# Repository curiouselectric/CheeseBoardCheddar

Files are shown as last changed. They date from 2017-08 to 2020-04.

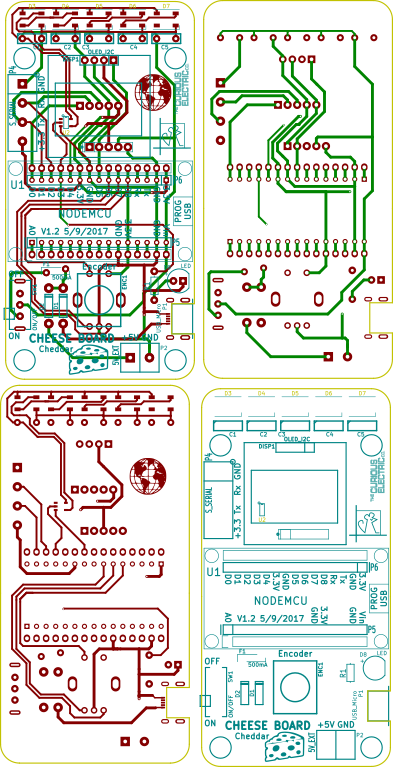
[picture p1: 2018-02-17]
CheeseBoardCheddar_Instructions/cheese_board_pcb.png

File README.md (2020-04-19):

# Cheese Board - Cheddar

This is an ESP8266 breakout board with small display, user inputs and WS2812 LEDs. 

This is designed as a low cost platform to quickly get started with projects with the ESP8266. We wanted to design something that got you up and running with your project idea quickly and easily.

The main processor is based upon the [ESP8266 system-on-chip from Espressif Systems](https://en.wikipedia.org/wiki/ESP8266).

This can be programmed via the Arduino IDE (or your favourite IDE).

This repository contains the design files, software and hardward files for this project.

We can supply this project in kit form from [The Curious Electric Company](https://www.curiouselectric.co.uk/) and Tindie.

This repository is for the hardware and instructions only. The software is available here:

https://github.com/curiouselectric/CheeseBoard_Software

## Instructions

The instructions are available in this folder as a .pdf

## PCB Overview

It is based upon the NodeMCU Amica ESP8266 module which is low-cost, easy to find and has all regulation and protection required.

There is a small I2C interfaced OLED screen on the unit for displaying data and options.

A rotary encoder is used to select various options and as the user interface.

There are five WS2812 LEDs which can be controlled via the ESP8266, along with a level shifter for good 5V operation.

A connection output is provided for HC12 wireless modules and access to a software serial output is provided through screw terminal pads.

This can be powered via USB-B or Micro-USB connector.

A screw-temrinal connector for 5V power is also supplied, if needed.

PCB design has been produced using [KiCAD](http://kicad-pcb.org/).

Hardware for the enclosure is also provided here.

### Pin Connections:

| Node MCU Conenction | Pin Number |Function | Arduino Alias |
|---|---|---|---|
| D0 | 30 | HC-12 SET pin | 16 |
| D1 | 29 | Soft Serial Tx | 5 |
| D2 | 28 | Soft Serial Rx | 4 |
| D3 | 27 | LED WS2812 | 0 |
| D4 | 26 | I2C SCLK | 2 |
| D5 | 23 | I2C SDA | 14 |
| D6 | 22 | Enocder B | 12 |
| D7 | 21 | Enocder A | 13 |
| D8 | 20 | Encoder Switch | 15 |
| D9 | 19 | H/W Serial Rx | 3 |
| D10 | 18 | H/W Serial Tx | 1 |
| A0 | 1 | N/C | A0 |

## Software Overview

This project has been designed with some interesting software to get you up and running. We wanted this project to do something useful or fun straight away. But it has been designed for hacking and for you to change, alter, adjust and play as you need.

## Hardware Overview

This kit comes with a simple enclosure to house the electronics.

This has been designed to be laser cut in 3mm acrylic. The design files are within this repository, if you would like to make your own or alter the design at all.

# To Do

* Check software in many applications
* Update instructions as required

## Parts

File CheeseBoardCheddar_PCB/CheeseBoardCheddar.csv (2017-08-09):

Reference | Value | Footprint | Datasheet | Description | Supplier 1 | Supplier 1 Part No | Supplier 1 Cost | Manufacturer | Manufacturer Part No
U1 | NODEMCU | REInnovationFootprint:NodeMCU_Amica_R2_FSILK | https://nodemcu.readthedocs.io/en/master/en/ | Node MCU Amica version. ESP8266 breakout. | AliExpress | https://www.aliexpress.com/item/Update-Industry-4-0-New-esp8266-NodeMCU-v2-Lua-WIFI-networking-development-kit-board-based-on/32358722888.html | 3.50
DISP1 | OLED_I2C | REInnovationFootprint:TH_OLED1306 |  | OLED display 128x64 IIC | Aliexpress | https://www.aliexpress.com/item/Free-Shipping-10pcs-2015-white-New-128X64-OLED-LCD-LED-Display-Module-0-96-I2C-IIC/32311828903.html | 2.75
D8 | LED | REInnovationFootprint:TH_LED-5MM_larg_pad |  |  |  |  | 0.05
P3 | SERIAL_HC12 | REInnovationFootprint:TH_SIL_5_HC12
R1 | 330 | REInnovationFootprint:TH_Resistor_1 |  |  |  |  | 0.01
SW1 | ON/OFF | REInnovationFootprint:SW_SPDT_R_Angle_ALIEX |  |  | Aliexpress |  | 0.2
F1 | 500mA | REInnovationFootprint:TH_MC36188_FUSE |  | Resettable fuse. 0.5A | RS | 517-6635 | 0.27
P6 | NODEMCU_2 | REInnovationFootprint:TH_SIL-15
P5 | NODEMCU_1 | REInnovationFootprint:TH_SIL-15
U2 | 74LVC1G17 | REInnovationFootprint:SM_SOT-23-5 | http://docs-europe.electrocomponents.com/webdocs/154d/0900766b8154d6d1.pdf |  | RS | 816-8763 | 0.06 | Nexperia | 74LVC1G17GV
P4 | S_SERIAL | matts_components:SIL-4_screw_terminals
P7 | PCB | REInnovationFootprint:PCB_50x100mm_RJWIFI
P10 | LOGO1 | CuriousElectric3:CEC_Globe_10mm_FCU
P11 | LOGO2 | CuriousElectric3:TCEC_Words_13mm
D1 | 1N5819 | REInnovationFootprint:TH_Diode_1 | https://www.diodes.com/assets/Datasheets/ds23001.pdf | 1A Schottky diode | RS | 917-9108 | 0.02 | HY Electronic Corp
ENC1 | Encoder | REInnovationFootprint:TH_Encoder |  | Rotary encoder | Aliexpress | https://www.aliexpress.com/item/Wholesale-20pcs-lot-12mm-Rotary-Encoder-Switch-W-Keyswitch-HQ-New-free-shipping-10000002/495026832.html | 0.50
P2 | 5V_EXT | matts_components:SIL-2_screw_terminal |  | Screw terminal conenctor | Aliexpress |  | 0.10
C1 | 100n | matts_components:C1_wide_lg_pad |  |  | Rapid | 10-3260 | 0.07
P1 | USB_Micro | REInnovationFootprint:USB_Micro-B_MOLEX_47642-0001 | http://docs-europe.electrocomponents.com/webdocs/144c/0900766b8144c28e.pdf | Micro USB connector | RS | 896-7419 | 0.60 | MOLEX | 47642-0001
D2 | 1N5819 | REInnovationFootprint:TH_Diode_1 | https://www.diodes.com/assets/Datasheets/ds23001.pdf | 1A Schottky diode | RS | 917-9108 | 0.02 | HY Electronic Corp
P9 | HARDWARE | CuriousElectric3:CEC_Globe_10mm_FCU
P8 | LOGO_MOUSE | CuriousElectric3:CEC_Globe_10mm_FCU
D3 | WS2812B_SMD | REInnovationFootprint:SM_WS2812B | https://www.kitronik.co.uk/pdf/WS2812B-LED-datasheet.pdf | WS2812B SMD 50_50 | AliExpress | https://www.aliexpress.com/item/10-1000pcs-WS2812B-4pins-5050-SMD-Black-White-version-WS2812-Individually-Addressable-Digital-RGB-LED-Chip/ | 0.10
D4 | WS2812B_SMD | REInnovationFootprint:SM_WS2812B | https://www.kitronik.co.uk/pdf/WS2812B-LED-datasheet.pdf | WS2812B SMD 50_50 | AliExpress | https://www.aliexpress.com/item/10-1000pcs-WS2812B-4pins-5050-SMD-Black-White-version-WS2812-Individually-Addressable-Digital-RGB-LED-Chip/ | 0.10
D5 | WS2812B_SMD | REInnovationFootprint:SM_WS2812B | https://www.kitronik.co.uk/pdf/WS2812B-LED-datasheet.pdf | WS2812B SMD 50_50 | AliExpress | https://www.aliexpress.com/item/10-1000pcs-WS2812B-4pins-5050-SMD-Black-White-version-WS2812-Individually-Addressable-Digital-RGB-LED-Chip/ | 0.10
D6 | WS2812B_SMD | REInnovationFootprint:SM_WS2812B | https://www.kitronik.co.uk/pdf/WS2812B-LED-datasheet.pdf | WS2812B SMD 50_50 | AliExpress | https://www.aliexpress.com/item/10-1000pcs-WS2812B-4pins-5050-SMD-Black-White-version-WS2812-Individually-Addressable-Digital-RGB-LED-Chip/ | 0.10
D7 | WS2812B_SMD | REInnovationFootprint:SM_WS2812B | https://www.kitronik.co.uk/pdf/WS2812B-LED-datasheet.pdf | WS2812B SMD 50_50 | AliExpress | https://www.aliexpress.com/item/10-1000pcs-WS2812B-4pins-5050-SMD-Black-White-version-WS2812-Individually-Addressable-Digital-RGB-LED-Chip/ | 0.10
C2 | 100n | matts_components:C1_wide_lg_pad |  |  | Rapid | 10-3260 | 0.07
C3 | 100n | matts_components:C1_wide_lg_pad |  |  | Rapid | 10-3260 | 0.07
C4 | 100n | matts_components:C1_wide_lg_pad |  |  | Rapid | 10-3260 | 0.07
C5 | 100n | matts_components:C1_wide_lg_pad |  |  | Rapid | 10-3260 | 0.07

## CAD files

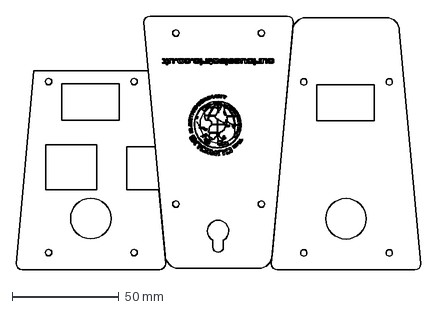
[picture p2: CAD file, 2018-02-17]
CheeseBoardCheddar_Hardware/Cheese Board Cheddar Enclosure Design_v2.dxf
189.4 x 118.8 mm

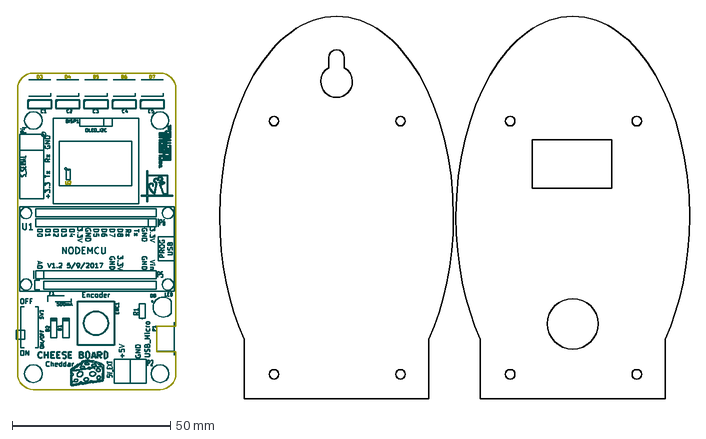
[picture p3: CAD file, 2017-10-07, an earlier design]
CheeseBoardCheddar_Hardware/OLD designs/Cheese Board Cheddar Enclosure Design.dxf
212.7 x 120.8 mm

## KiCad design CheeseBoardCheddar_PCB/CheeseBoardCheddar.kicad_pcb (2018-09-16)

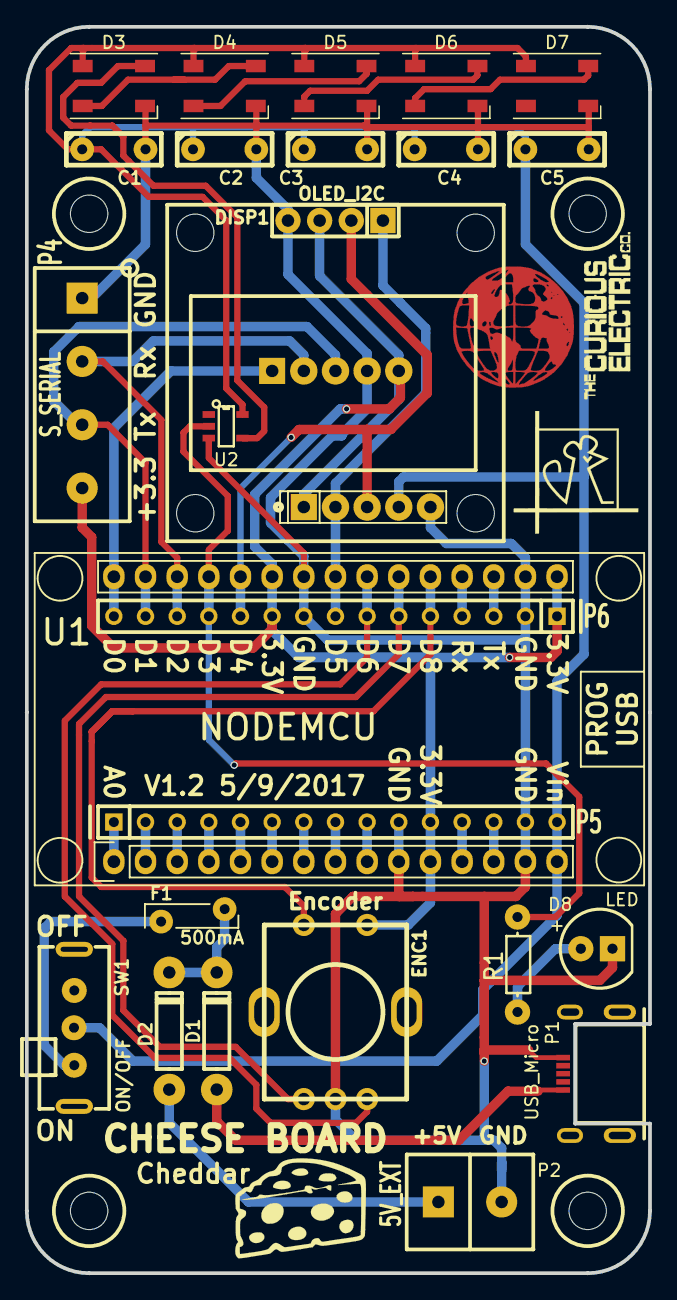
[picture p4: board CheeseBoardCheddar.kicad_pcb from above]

Board: 2 copper layers, 50.0 x 100.0 mm, 32 parts (0 on the bottom side), 35 nets.

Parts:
C1, C2, C3, C4, C5: 100n; C1_wide_lg_pad
D1, D2: 1N5819; TH_Diode_1
D3, D4, D5, D6, D7: WS2812B_SMD; SM_WS2812B
D8: LED; TH_LED-5MM_larg_pad
DISP1: OLED_I2C; TH_OLED1306
ENC1: Encoder; TH_Encoder
F1: 500mA; TH_MC36188_FUSE
P1: USB_Micro; USB_Micro-B_MOLEX_47642-0001
P2: 5V_EXT; SIL-2_screw_terminal
P3: SERIAL_HC12; TH_SIL_5_HC12
P4: S_SERIAL; SIL-4_screw_terminals
P5: NODEMCU_1; TH_SIL-15
P6: NODEMCU_2; TH_SIL-15
P7: PCB; PCB_50x100mm_RJWIFI
P8: LOGO_MOUSE; mouse10x10
P10: LOGO1; CEC_Globe_10mm_FCU
P11: LOGO2; TCEC_Words_13mm
P13: LOGO_CHEESE; CheeseWedge8mm
P14: I2C_EXT; SIL-5_large_pads_marker
R1: 330; TH_Resistor_1
SW1: ON/OFF; SW_SPDT_R_Angle_ALIEX
U1: NODEMCU; NodeMCU_Amica_R2_FSILK
U2: 74LVC1G17; SM_SOT-23-5

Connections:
+3V3: DISP1.3, ENC1.2, P3.5, P4.4, P5.11, P6.1, P6.10, P14.1, U1.11, U1.16, U1.25
/5V_PWR: C1.1, C2.1, C3.1, C4.1, C5.1, D3.1, D4.1, D5.1, D6.1, D7.1, P5.15, P14.4, SW1.2, U1.15, U2.5
/ENC_A: ENC1.A, P6.6, U1.21
/ENC_B: ENC1.B, P6.7, U1.22
/HC12_SET: P3.1, P6.15, U1.30
/LED_WS2811: P6.12, R1.1, U1.27, U2.2
/Rx: P6.4, U1.19
/SCL: DISP1.2, P6.11, P14.3, U1.26
/SDA: DISP1.1, P6.8, P14.2, U1.23
/SOFT_Rx: P3.2, P4.2, P6.13, U1.28
/SOFT_Tx: P3.3, P4.3, P6.14, U1.29
/SW_ENC: ENC1.1, P6.5, U1.20
/Tx: P6.3, U1.18
GND: C1.2, C2.2, C3.2, C4.2, C5.2, D3.3, D4.3, D5.3, D6.3, D7.3, D8.1, DISP1.4, ENC1.C, P1.5, P2.2, P3.4, P4.1, P5.10, P5.14, P6.2, P6.9, P14.5, U1.10, U1.14, U1.17, U1.24, U2.3
unnamed: D1.1, D2.1, F1.1
unnamed: D1.2, P1.1
unnamed: D2.2, P2.1
unnamed: D3.2, D4.4
unnamed: D3.4, U2.4
unnamed: D4.2, D5.4
unnamed: D5.2, D6.4
unnamed: D6.2, D7.4
unnamed: D8.2, R1.2
unnamed: F1.2, SW1.1
unnamed: P5.1, U1.1
unnamed: P5.2, U1.2
unnamed: P5.3, U1.3
unnamed: P5.4, U1.4
unnamed: P5.5, U1.5
unnamed: P5.6, U1.6
unnamed: P5.7, U1.7
unnamed: P5.8, U1.8
unnamed: P5.9, U1.9
unnamed: P5.12, U1.12
unnamed: P5.13, U1.13

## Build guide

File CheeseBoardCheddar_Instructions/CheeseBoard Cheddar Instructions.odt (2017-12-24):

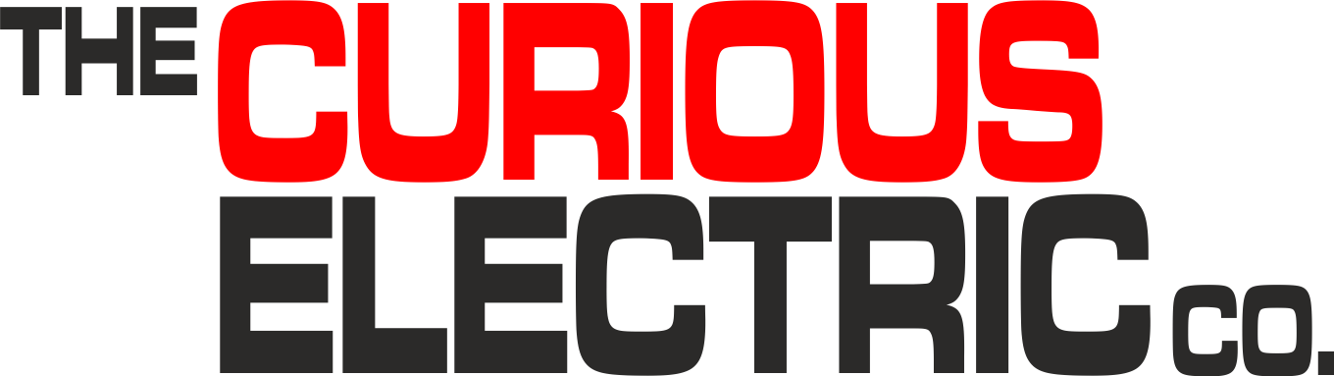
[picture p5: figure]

| Cheese Board: Cheddar Instructions

Date: | 24/09/17 | Version: | 1.0 | By: | Matt Little

This is an ESP8266 breakout board with small OLED display, a rotary encoder for user input and five Red-Green-Blue WS2812 LEDs.

This is designed as a low cost platform to quickly get started with projects with the ESP8266. We wanted to design something that got you up and running with your project idea quickly and easily.

The main processor is based upon the ESP8266 system-on-chip from Espressif Systems (https://en.wikipedia.org/wiki/ESP8266).

This can be programmed via the Arduino IDE (or your favourite IDE).

This is a reasonably simple kit which requires some soldering.

This kit requires a micro-USB lead for programming and powering the unit.

It should take 1-2 hours to build.

Not suitable for under 12 years old.

# Parts included:

# Enclosure Parts:

# Parts list:

Item | Ref | Quantity
Capacitors. 100nf | C1-5 | 5
Diode. 1N5819 | D1, D2 | 2
LED. WS2812 (pre soldered) | D3-7 | 5
LED. Red. NOT included | B8 | Not Included
Display. OLED. 0.96" With 4-way header | DISP1 | 1
Encoder | ENC1 | 1
Fuse. 500MA | F1 | 1
USB micro Socket (pre-soldered) | P1 | 1
2 way screw terminal. 5V | P2 | 1
HC-11 Serial. Optional | P3
Software Serial. Optional | P4
Node MCU header. 15 way. | P5, P6 | 2
PCB – with SMD parts soldered | | 1
330ohm Resistor | R1 | 1
Switch | SW1 | 1
NodeMCU with 2 x 15 way headers | U1
74LVC1G17 Level shifter (pre-soldered) | U2

# Hardware

Item | Ref | Quantity
M2 Machine screws. Plastic. 6mm long | | 2
M2 Nuts. Plastic | | 2
M2 Spacers. Plastic. 12mm long | | 2
M3 Machine screws. 6mm long | | 4
M3 Machine screws 12mm long | | 4
M3 Threaded Hex spacers. 8mm long | | 4
M3 Threaded Hex spacers. 15mm long | | 4
Front. Laser cut 3mm Frosted Acrylic | | 1
Spacer. Laser cut 3mm Black. Acrylic | | 1
Back. Laser cut 3mm Frosted Acrylic | | 1

# Tools required:

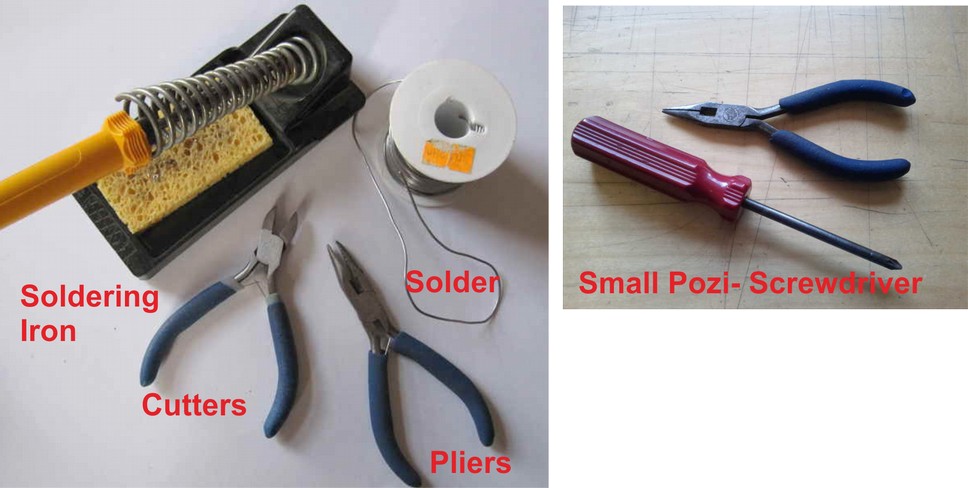
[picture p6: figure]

| | Long-nosed Pliers
Soldering Iron | | Posi-drive Screwdriver
Solder
Side cutters

Additional Items Required

- 1 x Micro-USB lead (for powering and for programming)
- 1 x 5V USB power supply (might be required for powering stand-alone unit)
- Computer with Arduino IDE and additional software installed. (see software section for more details)

Instructions:

Step: 1 | Solder capacitors

Step: 2 | Solder diodes

Step: 3 | Solder switch

Step: 4 | Solder header pins
| | For OLED and for NodeMCU

Step: 5 | Solder encoder

Step: 6 | Solder fuse

Step: 7 | Solder screw terminals (if needed)

Step: 8 | Fit LCD

Step: 9 | Fit Node MCU

Step: 10 | PCB is finished!

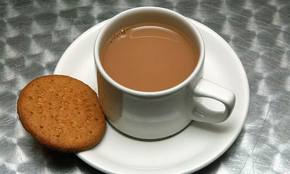
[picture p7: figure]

The NodeMCU has been pre-programmed with a test code. This should run when powered. Test with micro-USB cable. Switch on and check: LEDs light OLED screen shows data Rotary Encoder changes data on OLED This should prove that the functions of the PCB and the NodeMCU are working OK. | | Have a nice cup of tea.

Step: 11 | Add enclosure
Ad spacers

Step: 12 | Add enclosure
| | Add back

Step: 13 | Add enclosure
Add front and spacer

Step: 14 | Finished build!

# Software

Step: 15 | Upload software
This is where the fun begins! This project has software

# Contact details:

This kit has been designed and produced by:

The Curious Electric Company

hello@curiouselectric.co.uk

www.curiouselectric.co.uk

Hopkinson Gallery, 21 Station Street, Nottingham, UK, NG2 3AJ

We would like you to be happy with this kit. If you are not happy for any reason then please contact us and we will help to sort it out.

Please email hello@curiouselectric.co.uk with any questions or comments.

Please tweet us at @curiouselectric

If any parts are missing from your kit then please email hello@curiouselectric.co.uk with details, including when and where the kit was purchased.

More technical information can be found via www.curiouselectric.co.uk

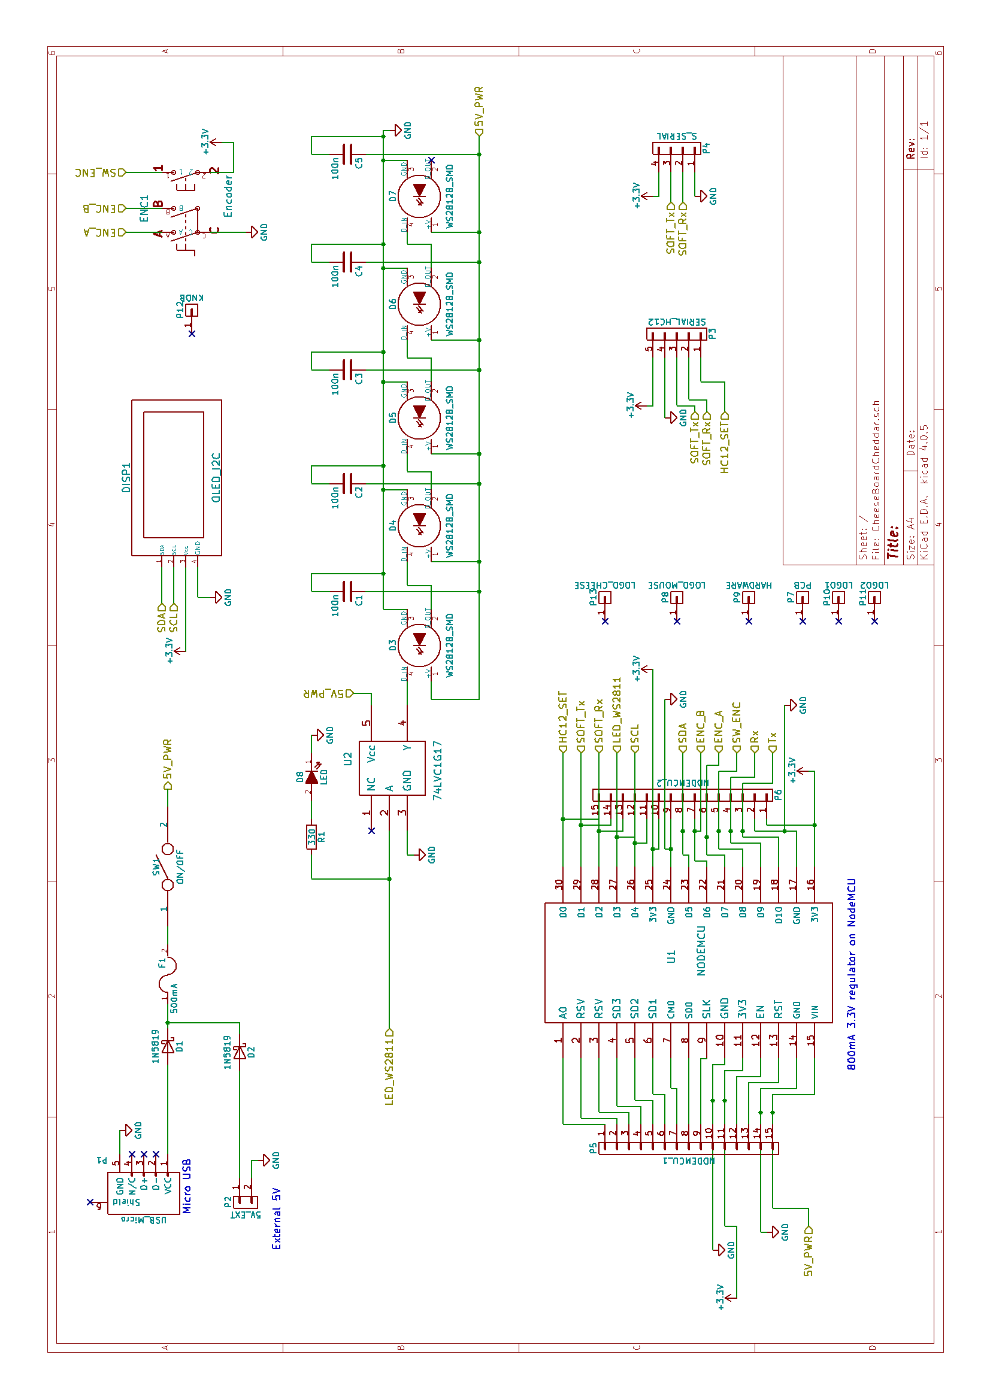
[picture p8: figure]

# Circuit Schematic:

# PCB Design:

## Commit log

2017-08-03 Initial commit of basic PCB files
    [ESP_WiFi_Display.kicad_pcb, ESP_WiFi_Display.sch]
2017-08-03 Update of Readme and PCB changed
    [ESP_WiFi_Display.sch]
2017-08-07 PCB changes
    [ESP_WiFi_Display.kicad_pcb, ESP_WiFi_Display.sch]
2017-08-08 Small PCB changes
    [ESP_WiFi_Display.kicad_pcb, ESP_WiFi_Display.sch]
2017-08-09 PCB initial wiring. Cost and Parts info done
    [ESP_WiFi_Display.csv, ESP_WiFi_Display.kicad_pcb, ESP_WiFi_Display.sch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]
2017-08-11 Full review of boards - needs NAME still!
    [ESP_WiFi_Display-B.Cu.gbr, ESP_WiFi_Display-B.Mask.gbr, ESP_WiFi_Display-B.SilkS.gbr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]
2017-09-05 Updated PCB with name
    [ESP_WiFi_Display-B.Cu.gbr, ESP_WiFi_Display-B.Mask.gbr, ESP_WiFi_Display-B.SilkS.gbr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]
2017-09-06 Update with new name
    [CheeseBoardCheddar-B.Cu.gbr, CheeseBoardCheddar-B.Mask.gbr, CheeseBoardCheddar-B.SilkS.gbr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]
2017-09-06 Slight update of silkscreen on PCB
    [CheeseBoardCheddar-B.Cu.gbr, CheeseBoardCheddar-B.Mask.gbr, CheeseBoardCheddar-B.SilkS.gbr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]
2017-09-24 Updated PCB with Encoder switch sorted
    [CheeseBoardCheddar-B.Cu.gbr, CheeseBoardCheddar-B.Mask.gbr, CheeseBoardCheddar-B.SilkS.gbr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]
2017-10-07 Updated enclosure design
    [Cheese Board Cheddar Enclosure Design.dxf]
2017-11-05 Updated enclsoure
    [Cheese Board Cheddar Enclosure Design_v2.dxf, CheeseBoardCheddar.xlsx]
2017-12-02 Added I2C bus to PCB
    [CheeseBoardCheddar.kicad_pcb, CheeseBoardCheddar.sch]
2017-12-24 Update of instructions
    [CheeseBoardCheddar-B.Cu.gbr, CheeseBoardCheddar-B.Mask.gbr, CheeseBoardCheddar-B.SilkS.gbr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]
2018-02-17 Updated instructions and .dxf files
    [Cheese Board Cheddar Enclosure Design_v2.dxf, CheeseBoardCheddar.kicad_pcb]
2018-09-16 Small Changes
    [CheeseBoardCheddar.kicad_pcb, CheeseBoardCheddar.xlsx]
